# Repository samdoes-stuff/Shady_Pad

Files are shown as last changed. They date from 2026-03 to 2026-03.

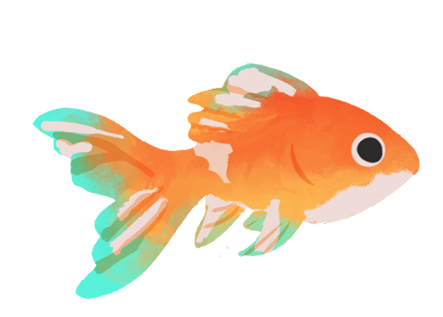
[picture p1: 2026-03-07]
SilkScreen/fish.png

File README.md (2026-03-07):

# Shady Pad
It is 3x3 custom sized 8 key macropad for app shortcuts equipped with a 0.91 inch display and EC11 encoder

## Usage
To use, one should flash their xiao rp2040 with the correct circuitpython .uf2 file, upload the code file, as well as libraries and linked images, save, and you're good to go! you can customize what each key does, lighting color, text displays, etc all within the code.py file

## Cad




## PCB






## Schematic



I later did not used LEDs in my PCB
## Firmware
- KMK based,
- Screen used for identifying layers, icon display, and signature display
- Custom rotary encoder decoding software from one analog pin
- Custom Key object designed for the rotary encoder multi function button
- Advanced use of macros and hotkeys for daily use
## BOM
Please refer to BOM.csv

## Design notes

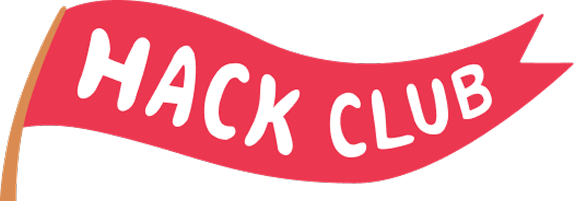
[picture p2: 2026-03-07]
SilkScreen/hackc club flag.png

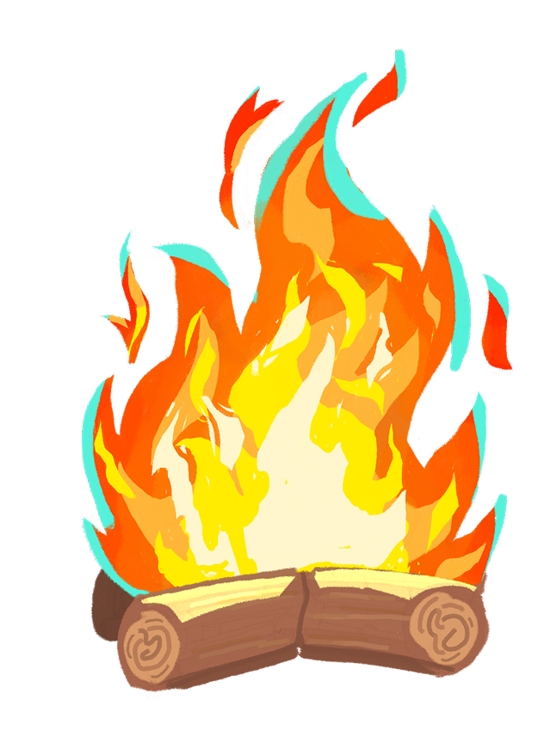
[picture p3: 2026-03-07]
SilkScreen/fire.png

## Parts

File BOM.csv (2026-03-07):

Qty | Item | Notes
1 | SEEEDUINO XIAO RP2040 | Microcontroller board
8 | MX-style switches | 5-pin preferred
9 | 1N4148 through-hole diodes | For switch matrix
1 | SSD1306 128x32 OLED 0.91 | I2C display
8 | Blank DSA keycaps
1 | EC11 rotary encoder

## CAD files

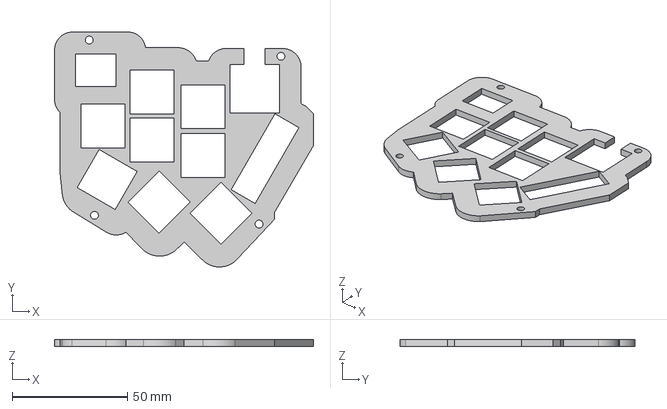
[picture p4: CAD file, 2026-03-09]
CAD File/Top_Case.step
112.3 x 101.9 x 3.00 mm

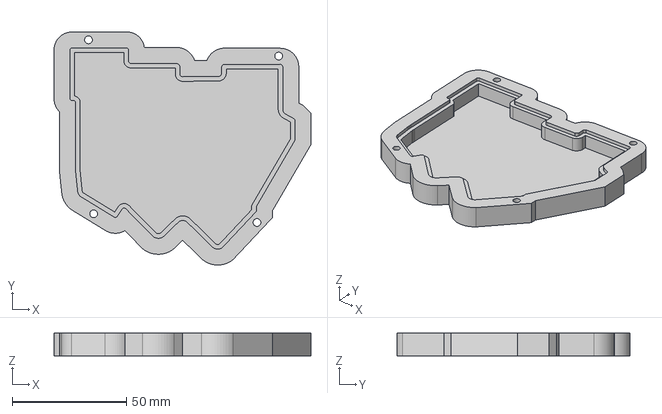
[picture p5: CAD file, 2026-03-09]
CAD File/Shady_Pad Bottom Case.step
112.3 x 101.9 x 10.0 mm

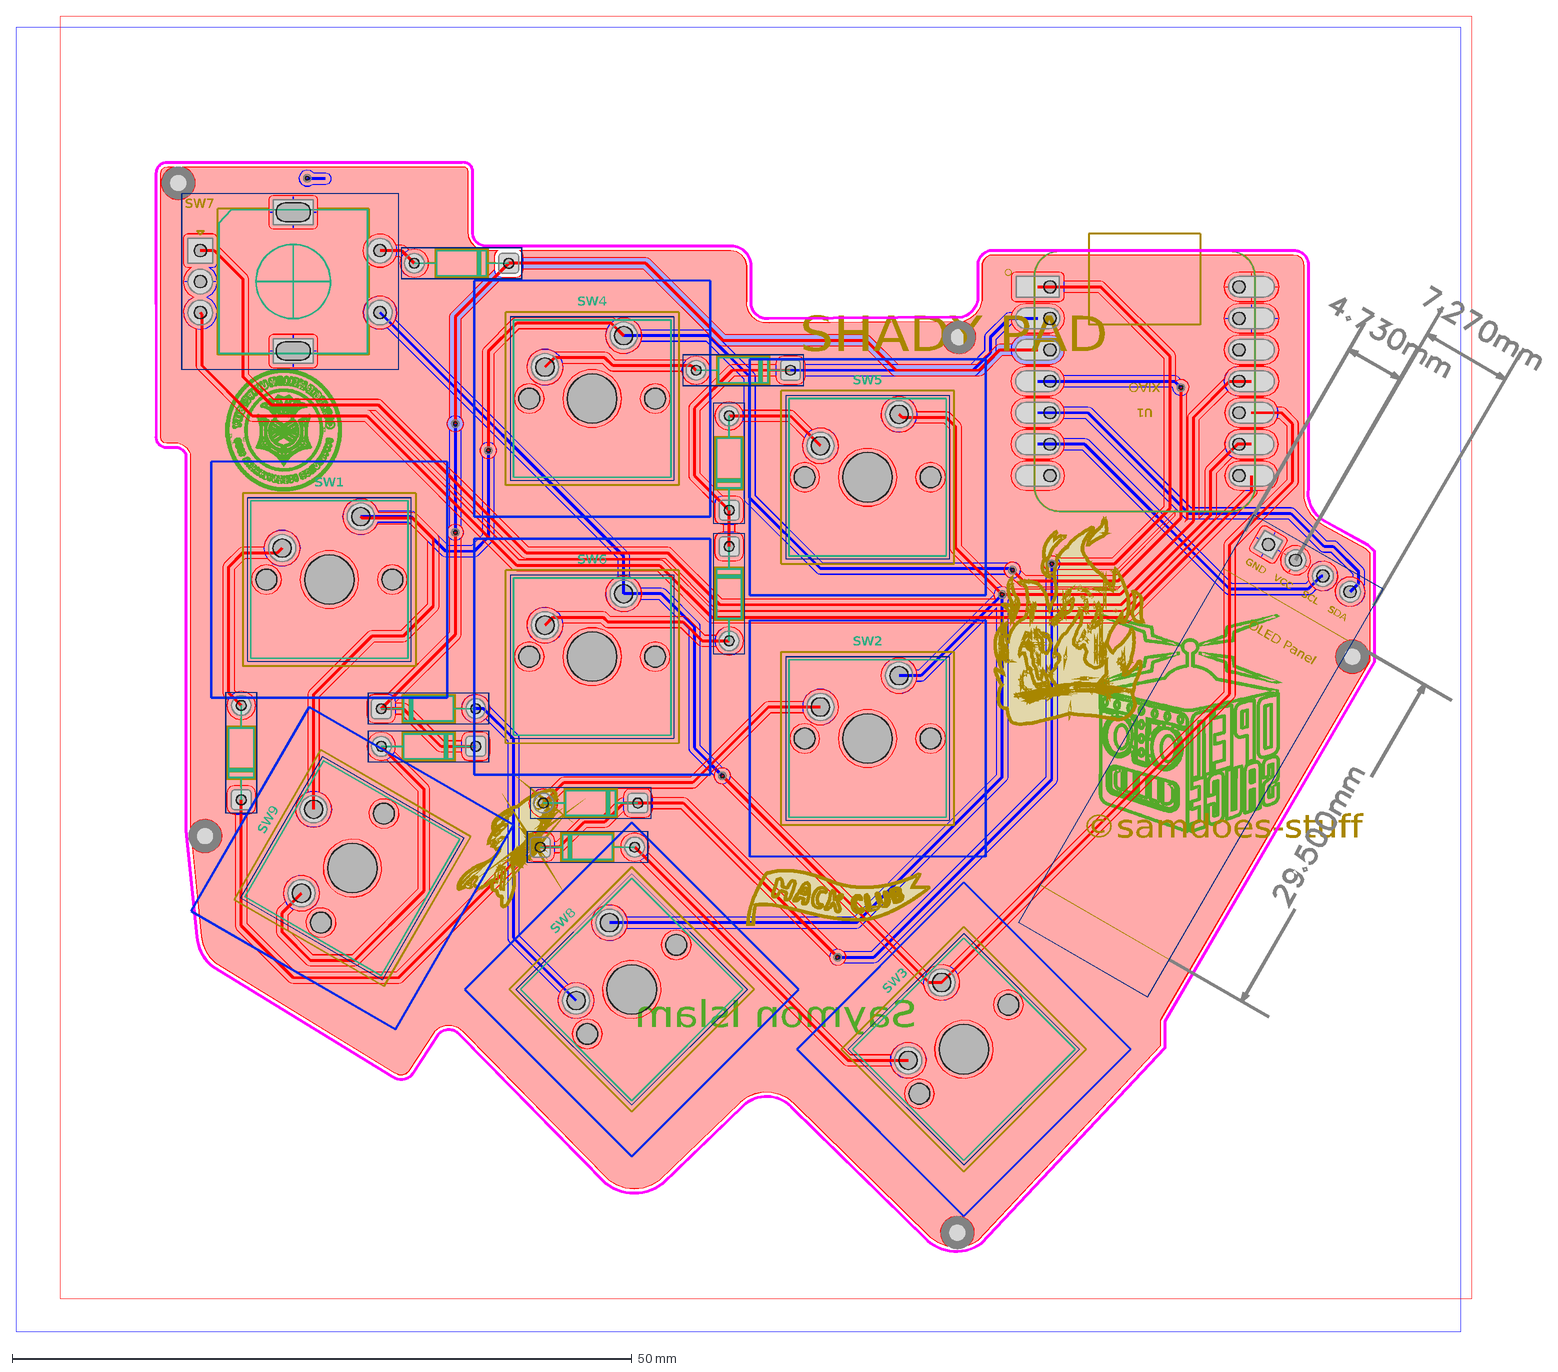
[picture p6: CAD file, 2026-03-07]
CAD File/DXF_Shady Pad_2026-03-07_AutoCAD2007.dxf
Saymon Islam
SHADY PAD
©️samdoes-stuff
SW5
SW3
SW6
SW1
SW2
SDA
SCL
GND
VCC
OLED Panel
SW7
SW8
U1
XIAO
SW4
SW9

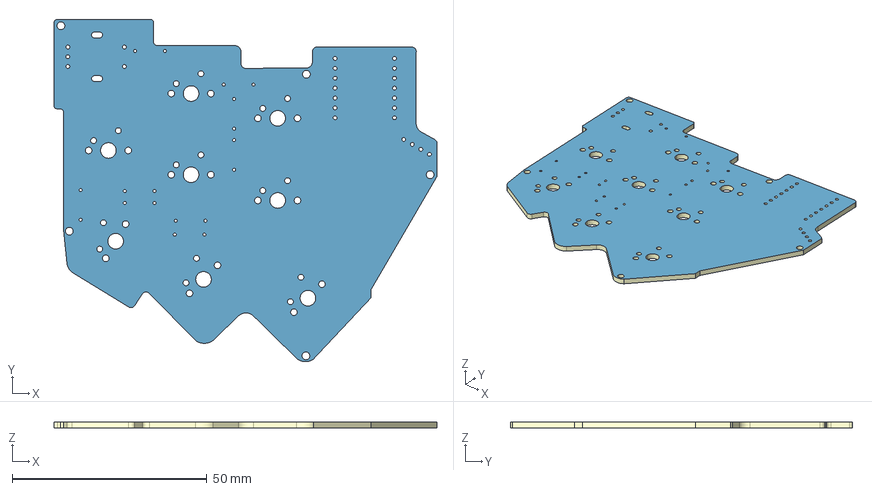
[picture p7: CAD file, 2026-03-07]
CAD File/3D_Shady Pad_2026-03-07.step
98.3 x 87.9 x 1.60 mm
Board~K78b
TopCopper~K78b
BottomCopper~K78b
TopFpcStiffener~K78b
BottomFpcStiffener~K78b

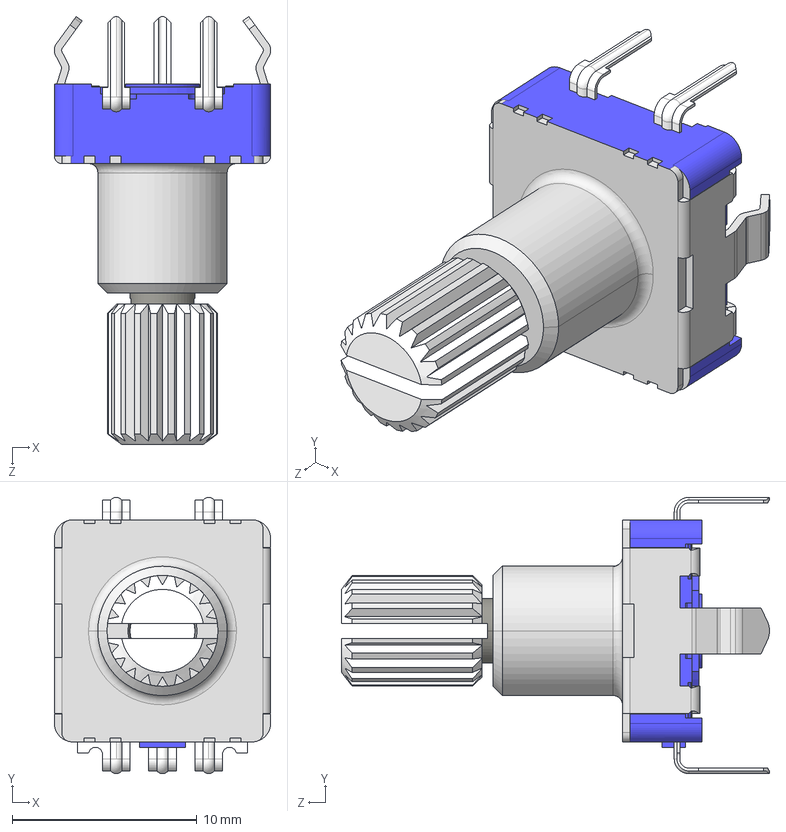
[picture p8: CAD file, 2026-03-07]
CAD File/EC11 Rotary Encoder Dode Switch-15mm .STEP
11.7 x 15.0 x 23.2 mm

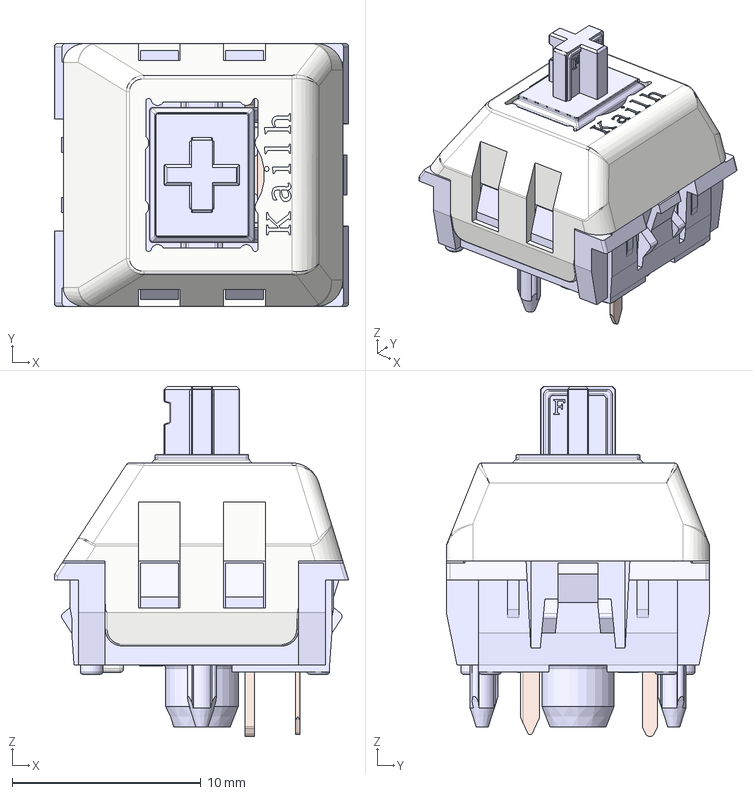
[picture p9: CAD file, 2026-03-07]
CAD File/Kailh Polia.step
15.6 x 14.0 x 18.5 mm
Housing
ThickContact
SpringContact
Stem
Lid

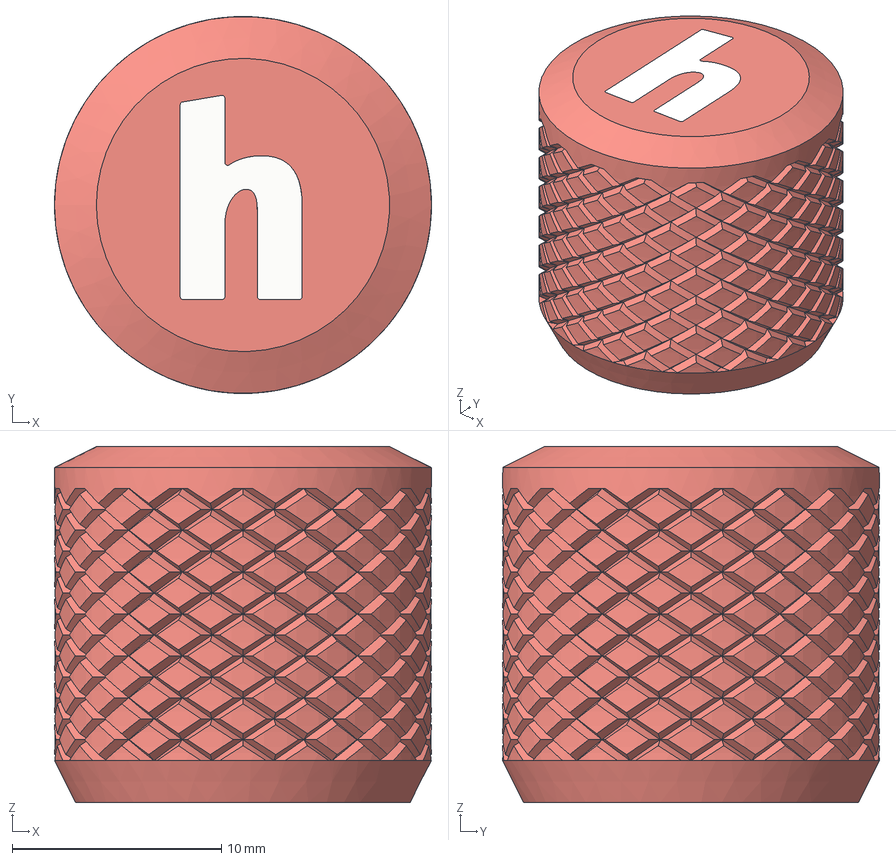
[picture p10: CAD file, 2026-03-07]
CAD File/knurled_knob.step
18.0 x 18.0 x 17.0 mm
Base
H

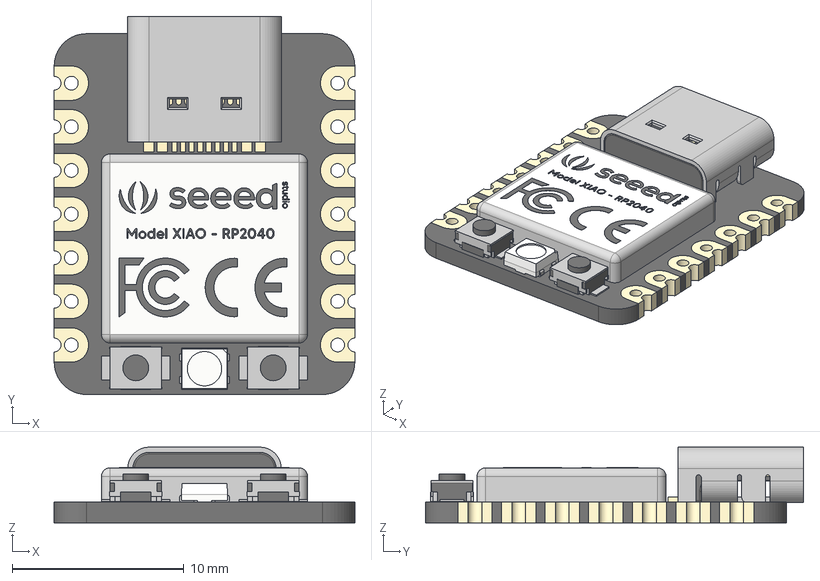
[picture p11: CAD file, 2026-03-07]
CAD File/Seeed Studio XIAO RP2040 v26.step
17.5 x 22.0 x 4.40 mm
type-c v2
smd_button v3
DOUT
DIN
VSS
VDD
smd_button v3(Mirror)

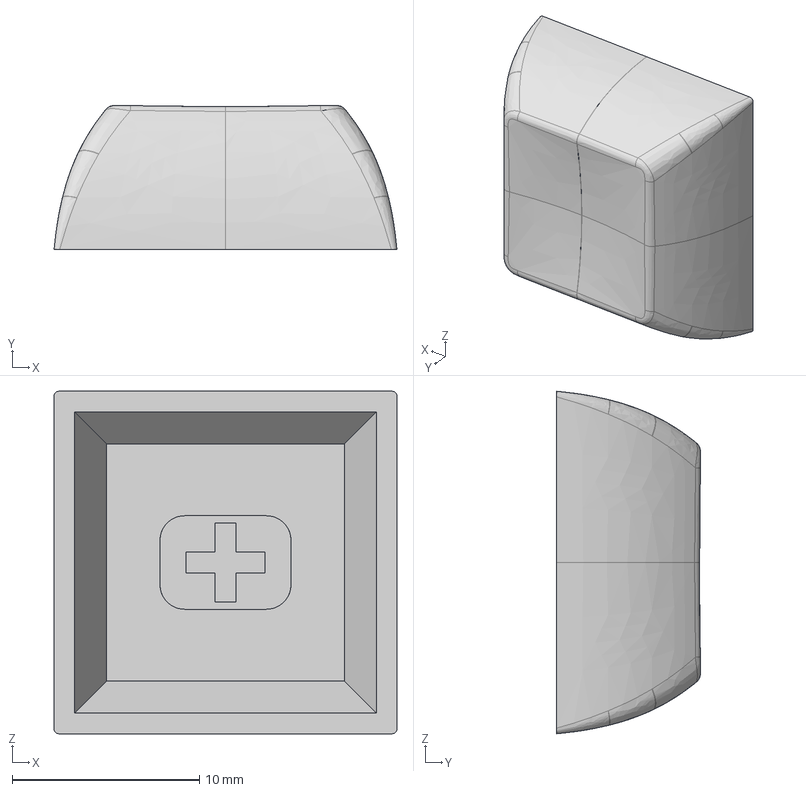
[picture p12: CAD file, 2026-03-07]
CAD File/DSA_Keycap_CherryMX.step
18.3 x 7.69 x 18.3 mm

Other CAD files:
CAD File/Shady_Pad Bottom Case.f3d
CAD File/Top_Case.f3d

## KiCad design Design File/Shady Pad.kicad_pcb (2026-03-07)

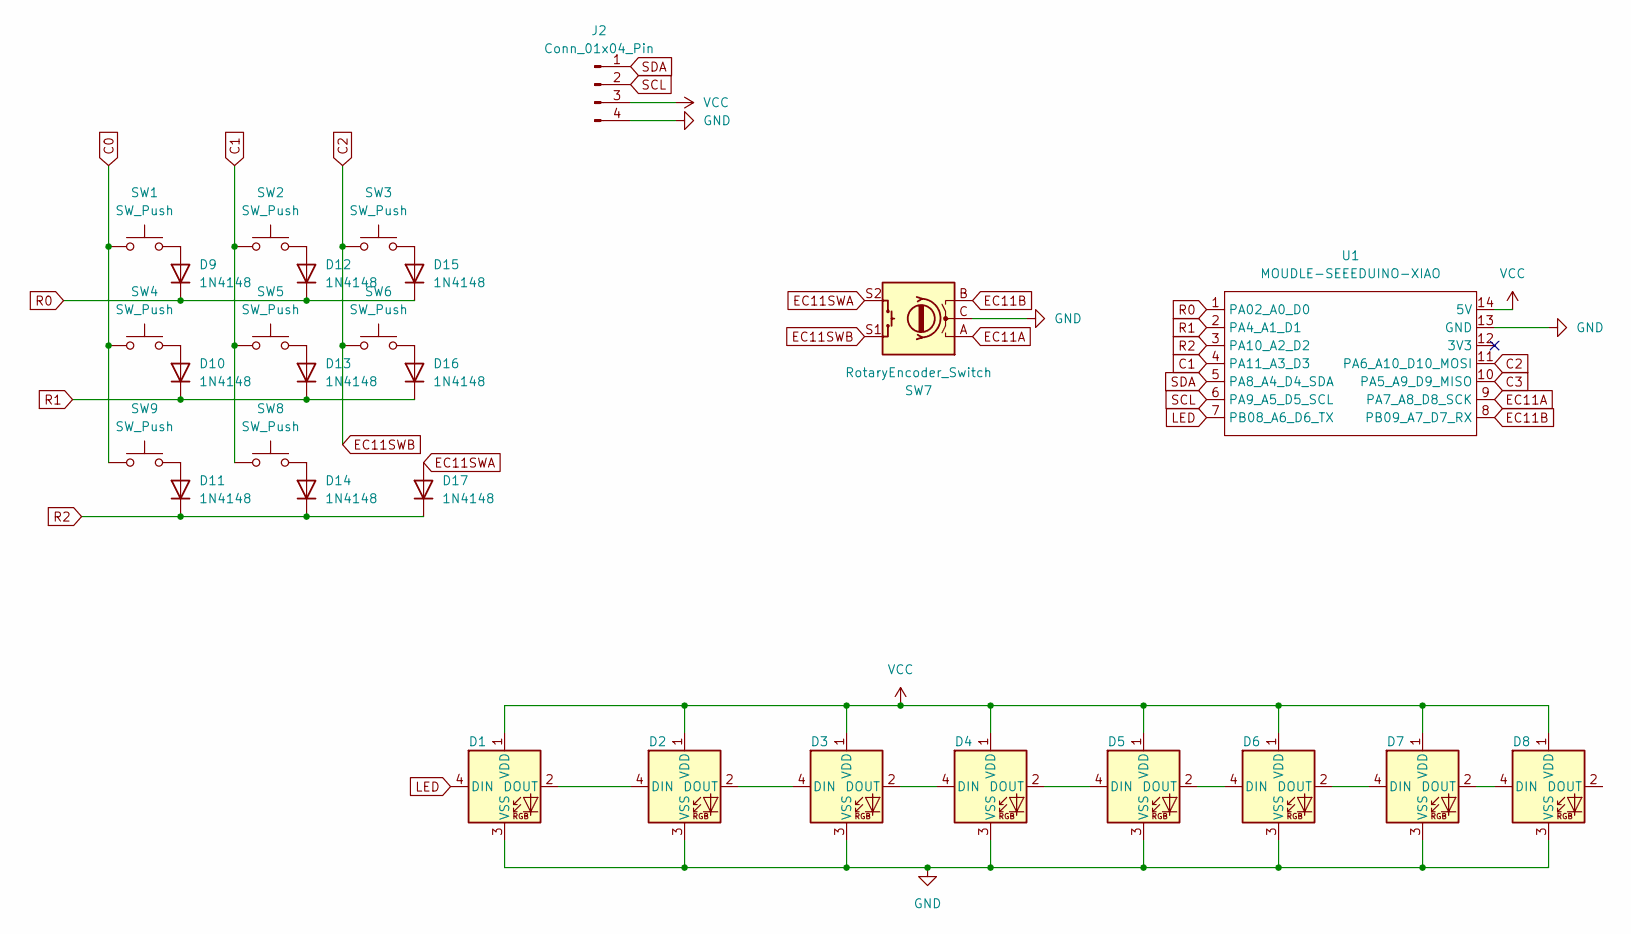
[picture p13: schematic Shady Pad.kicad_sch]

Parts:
D1, D2, D3, D4, D5, D6, D7, D8: SK6812MINI-E_fixed
D9, D10, D11, D12, D13, D14, D15, D16, D17: 1N4148; D_DO-35_SOD27_P7.62mm_Horizontal
J2: Conn_01x04_Pin; SSD1306-0.91-OLED-4pin-128x32
SW1, SW2, SW3, SW4, SW5, SW6, SW8, SW9: SW_Push; SW_Cherry_MX_1.00u_PCB
SW7: RotaryEncoder_Switch; RotaryEncoder_Alps_EC11E-Switch_Vertical_H20mm
U1: MOUDLE-SEEEDUINO-XIAO; XIAO-Generic-Hybrid-14P-2.54-21X17.8MM

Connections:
C0: SW1.1, SW4.1, SW9.1
C1: SW2.1, SW5.1, SW8.1, U1.4 (PA11_A3_D3)
C2: SW3.1, SW6.1, SW7.S1, U1.11 (PA6_A10_D10_MOSI)
C3: U1.10 (PA5_A9_D9_MISO)
EC11A: SW7.A, U1.9 (PA7_A8_D8_SCK)
EC11B: SW7.B, U1.8 (PB09_A7_D7_RX)
EC11SWA: D17.2 (A), SW7.S2
GND: D1.3 (VSS), D2.3 (VSS), D3.3 (VSS), D4.3 (VSS), D5.3 (VSS), D6.3 (VSS), D7.3 (VSS), D8.3 (VSS), J2.4, SW7.C, SW7.MP, U1.13 (GND)
LED: D1.4 (DIN), U1.7 (PB08_A6_D6_TX)
unnamed: D1.2 (DOUT), D2.4 (DIN)
unnamed: D2.2 (DOUT), D3.4 (DIN)
unnamed: D3.2 (DOUT), D4.4 (DIN)
unnamed: D4.2 (DOUT), D5.4 (DIN)
unnamed: D5.2 (DOUT), D6.4 (DIN)
unnamed: D6.2 (DOUT), D7.4 (DIN)
unnamed: D7.2 (DOUT), D8.4 (DIN)
unnamed: D9.2 (A), SW1.2
unnamed: D10.2 (A), SW4.2
unnamed: D11.2 (A), SW9.2
unnamed: D12.2 (A), SW2.2
unnamed: D13.2 (A), SW5.2
unnamed: D14.2 (A), SW8.2
unnamed: D15.2 (A), SW3.2
unnamed: D16.2 (A), SW6.2
R0: D9.1 (K), D12.1 (K), D15.1 (K), U1.1 (PA02_A0_D0)
R1: D10.1 (K), D13.1 (K), D16.1 (K), U1.2 (PA4_A1_D1)
R2: D11.1 (K), D14.1 (K), D17.1 (K), U1.3 (PA10_A2_D2)
SCL: J2.2, U1.6 (PA9_A5_D5_SCL)
SDA: J2.1, U1.5 (PA8_A4_D4_SDA)
VCC: D1.1 (VDD), D2.1 (VDD), D3.1 (VDD), D4.1 (VDD), D5.1 (VDD), D6.1 (VDD), D7.1 (VDD), D8.1 (VDD), J2.3, U1.14 (5V)

Board: 2 copper layers, 28 parts (0 on the bottom side), 29 nets, no tracks yet.

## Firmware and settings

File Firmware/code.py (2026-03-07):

import board
import busio
import analogio

from kmk.kmk_keyboard import KMKKeyboard
from kmk.keys import KC
from kmk.scanners import DiodeOrientation
from kmk.scanners.keypad import MatrixScanner, KeysScanner
from kmk.modules import Module

from kmk.extensions.display import Display, TextEntry
from kmk.extensions.display.ssd1306 import SSD1306


class AnalogEncoder(Module):
    def __init__(self, pin, thresholds, cw, ccw):
        self.pin = pin
        self.thresholds = thresholds
        self.cw = cw
        self.ccw = ccw
        self.ain = None
        self.last = None

    def during_bootup(self, keyboard):
        self.ain = analogio.AnalogIn(self.pin)

    def before_matrix_scan(self, keyboard):
        val = self.ain.value
        state = self.get_state(val)

        if self.last is not None and state != self.last:
            if self.last == 3:
                if state == 2:
                    keyboard.tap_key(self.ccw)
                elif state == 1:
                    keyboard.tap_key(self.cw)

        self.last = state
        return keyboard

    def get_state(self, v):
        for i, t in enumerate(self.thresholds):
            if v < t:
                return i
        return len(self.thresholds)

    def after_matrix_scan(self, keyboard): return keyboard
    def before_hid_send(self, keyboard): return
    def after_hid_send(self, keyboard): return
    def on_powersave_enable(self, keyboard): return
    def on_powersave_disable(self, keyboard): return


keyboard = KMKKeyboard()

keyboard.matrix = [
    MatrixScanner(
        column_pins=(board.D1, board.D2, board.D3),
        row_pins=(board.D7, board.D8, board.D9),
        columns_to_anodes=DiodeOrientation.ROW2COL
    ),
    KeysScanner(
        pins=[board.D10],
        value_when_pressed=False,
    ),
]

encoder = AnalogEncoder(
    pin=board.A0,
    thresholds=[1270, 10000, 40000],
    cw=KC.VOLU,
    ccw=KC.VOLD
)

keyboard.modules.append(encoder)


# OLED
i2c = busio.I2C(board.SCL, board.SDA)

driver = SSD1306(i2c=i2c)

display = Display(
    display=driver,
    width=128,
    height=32
)

display.entries = [
    TextEntry(text="ShadyPad", x=0, y=0),
    TextEntry(text="Ready", x=0, y=12),
]

keyboard.extensions.append(display)


keyboard.keymap = [
    [
        KC.A, KC.B, KC.C,
        KC.D, KC.E, KC.F,
        KC.G, KC.H, KC.I,
        KC.MUTE
    ]
]


if __name__ == "__main__":
    keyboard.go()

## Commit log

2026-03-07 Add BOM.csv with components and quantities
    [BOM.csv]
2026-03-07 Update quantities in BOM.csv
    [BOM.csv]
2026-03-07 Update BOM section in README.md
    Removed detailed BOM list and added BOM section header.
2026-03-07 Correct key count and add CAD, PCB, Schematic sections
    Updated the description to reflect the correct number of keys and added sections for CAD, PCB, and Schematic with images.
